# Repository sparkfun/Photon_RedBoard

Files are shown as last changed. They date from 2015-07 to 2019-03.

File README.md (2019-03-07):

SparkFun Photon RedBoard
========================================

SparkFun Photon RedBoard

[*SparkFun Photon RedBoard (DEV-13321)*](https://www.sparkfun.com/products/13321)

The SparkFun Photon RedBoard is a Particle Cloud-compatible WiFi development board. It can be programmed over-the-air, using Particle's Build IDE. It's like a Photon, but Arduino-shaped and red!

Repository Contents
-------------------

* **/Documentation** - Data sheets, additional product information
* **/Hardware** - Eagle design files (.brd, .sch)
* **/Production** - Production panel files (.brd)

Documentation
--------------
* **[Hookup Guide](https://learn.sparkfun.com/tutorials/photon-redboard-hookup-guide)** - Basic hookup guide for the SparkFun Photon RedBoard.
* **[Experiment Guide](https://learn.sparkfun.com/tutorials/photon-redboard-hookup-guide)** - Experiment guide for the SparkFun Photon RedBoard to send and receive data over WiFi.
* **[SparkFun Fritzing repo](https://github.com/sparkfun/Fritzing_Parts)** - Fritzing diagrams for SparkFun products.
* **[SparkFun 3D Model repo](https://github.com/sparkfun/3D_Models)** - 3D models of SparkFun products. 

Product Versions
----------------
* [DEV-13321](https://www.sparkfun.com/products/13321) - **Photon RedBoard**: Initial release of the SparkFun Photon RedBoard.
* [KIT-13320](https://www.sparkfun.com/products/13320) - **SparkFun Inventor's Kit for Photon**: A SparkFun Inventor's Kit based around the Photon RedBoard.

Version History
---------------
* [V_1.0](https://github.com/sparkfun/Photon_RedBoard/tree/V_1.0) - Initial hardware release - 1.0.

License Information
-------------------

This product is _**open source**_! 

Please review the LICENSE.md file for license information. 

If you have any questions or concerns on licensing, please contact techsupport@sparkfun.com.

Distributed as-is; no warranty is given.

- Your friends at SparkFun.

_<COLLABORATION CREDIT>_

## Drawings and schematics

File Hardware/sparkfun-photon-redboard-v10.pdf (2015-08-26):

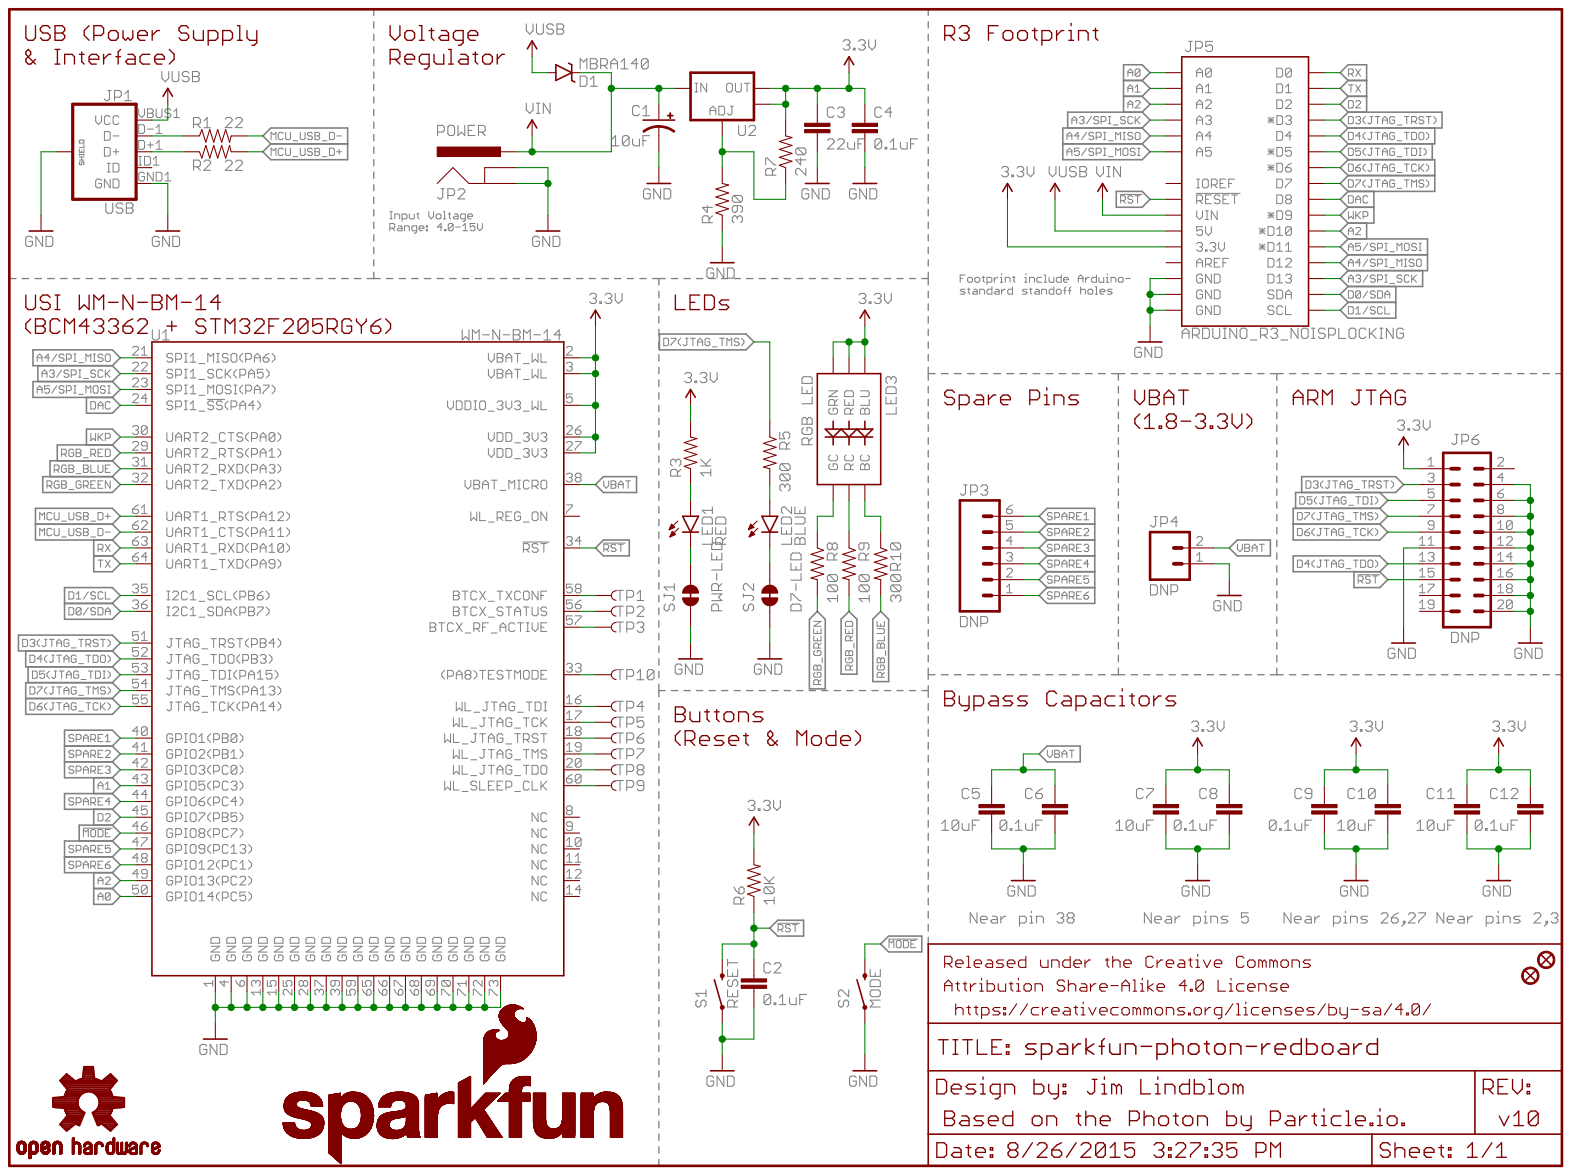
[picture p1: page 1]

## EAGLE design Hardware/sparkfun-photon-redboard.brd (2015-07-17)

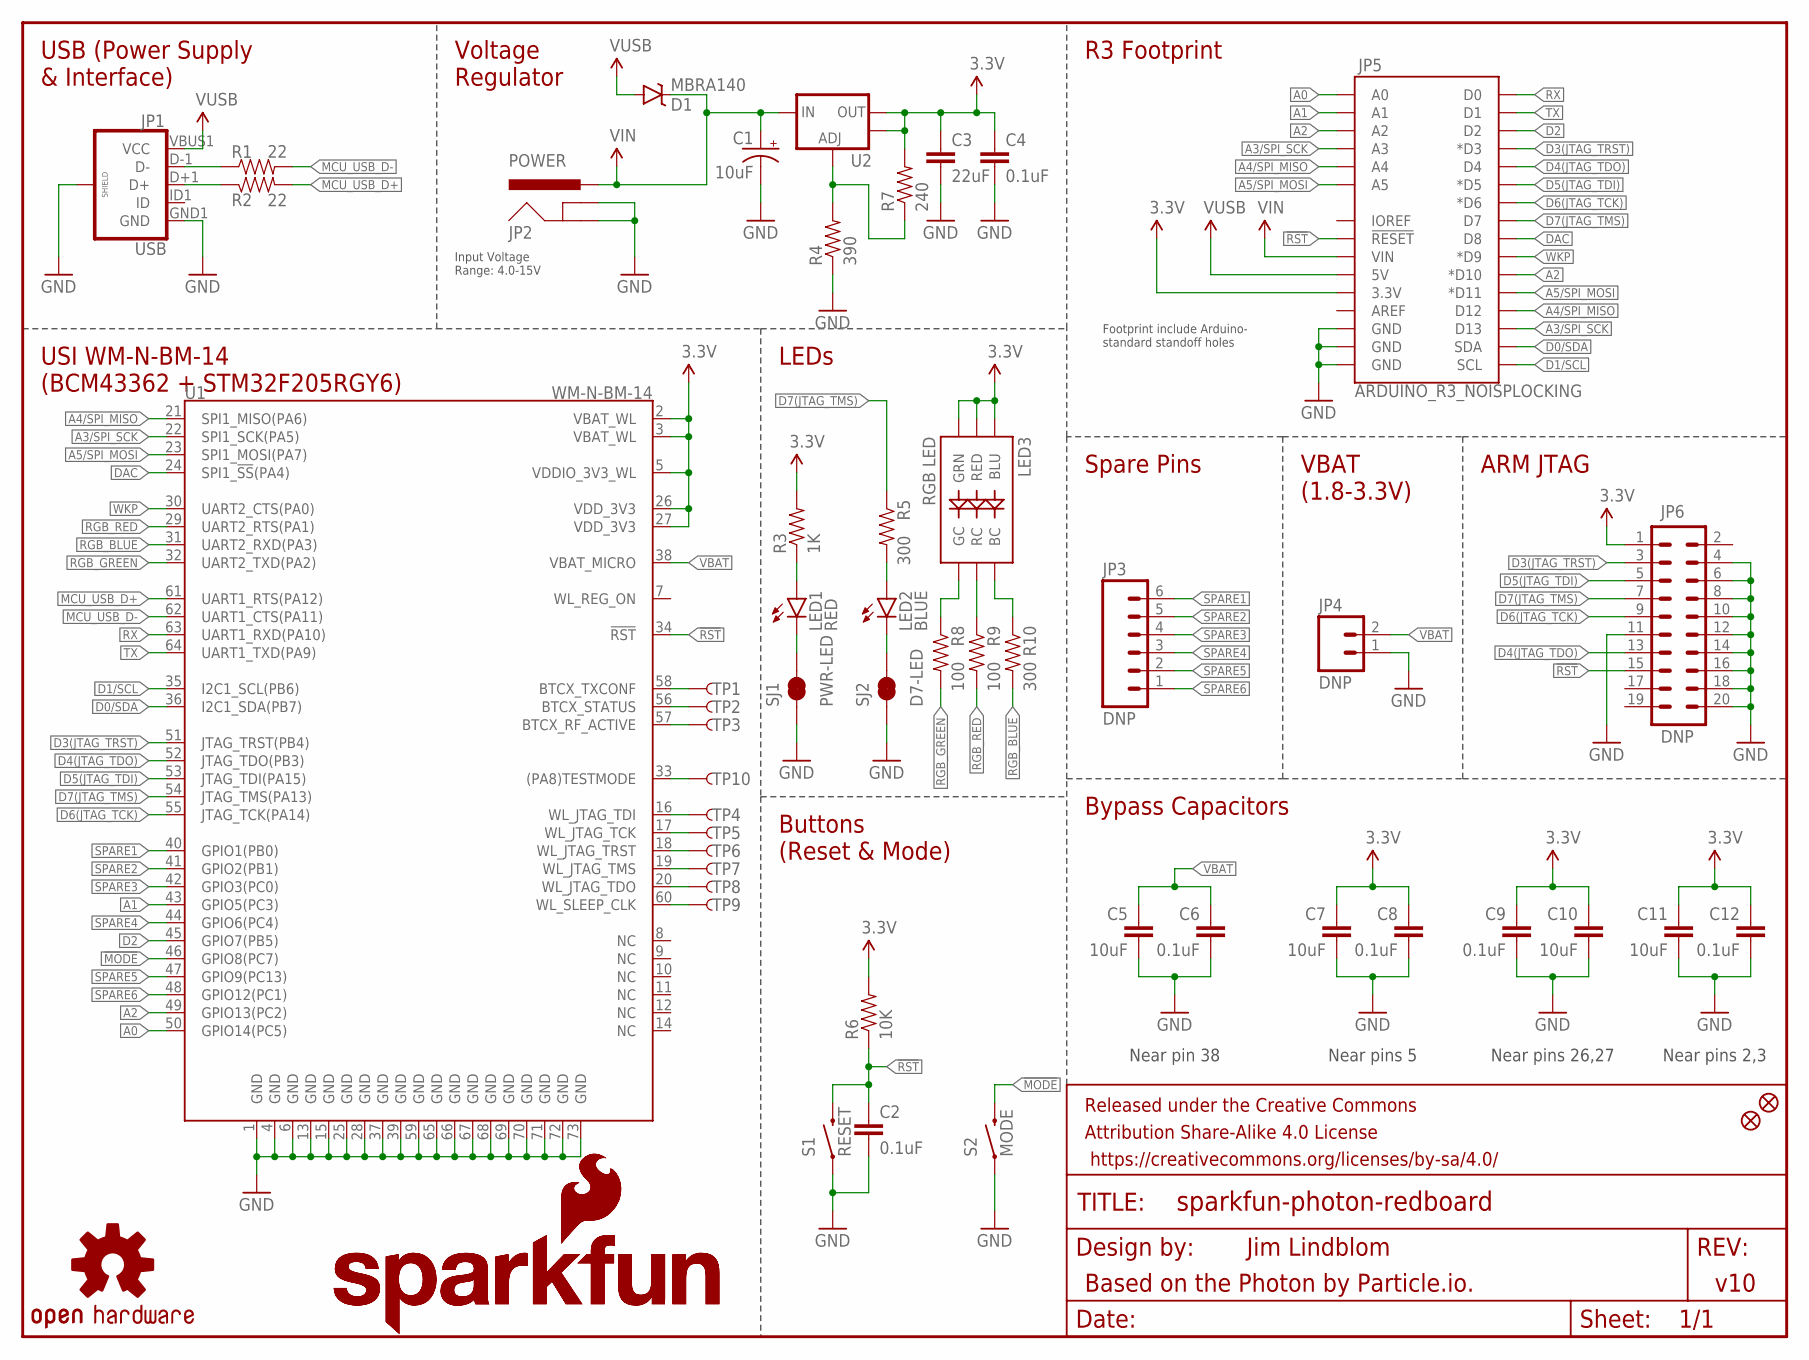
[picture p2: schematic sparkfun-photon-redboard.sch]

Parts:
C1: 10uF; EIA3216
C2, C4, C6, C8, C9, C12: 0.1uF; 0603-CAP
C3: 22uF; 0805
C5, C7, C10, C11: 10uF; 0603-CAP
D1: MBRA140; SMA-DIODE
FID1, FID2: FIDUCIAL1X2; FIDUCIAL-1X2
FRAME1: FRAME-LETTER; CREATIVE_COMMONS
JP1: USB; USB-B-MICRO-SMD_V03
JP2: POWER; POWER_JACK_PTH_LOCK
JP3: DNP; 1X06
JP4: DNP; 1X02
JP5: ARDUINO_R3_NOISPLOCKING; ARDUINO_R3_NOISP_LOCKING
JP6: DNP; 2X10
LED1: RED; LED-1206
LED2: BLUE; LED-1206
LED3: RGB LED; PLCC-6-LED
LOGO1: OSHW-LOGOM; OSHW-LOGO-M
LOGO2: SFE_LOGO_NAME_FLAME.2_INCH; SFE_LOGO_NAME_FLAME_.2
LOGO3: SFE_LOGO_NAME_FLAME.4_INCH; SFE_LOGO_NAME_FLAME_.4
R1, R2: 22; 0603-RES
R3: 1K; 0603-RES
R4: 390; 0603-RES
R5, R10: 300; 0603-RES
R6: 10K; 0603-RES
R7: 240; 0603-RES
R8, R9: 100; 0603-RES
S1: RESET; TACTILE-PTH
S2: MODE; TACTILE-PTH
SJ1: PWR-LED; PAD-JUMPER-2-NC_BY_TRACE_YES_SILK
SJ2: D7-LED; PAD-JUMPER-2-NC_BY_TRACE_YES_SILK
TP1, TP2, TP3, TP4, TP5, TP6, TP7, TP8, TP9, TP10: TEST-POINTTP_15TH_THRU; TP_15TH
U1: WM-N-BM-14
U2: V_REG_LM1117SOT223; SOT223

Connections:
3.3V: C3.1, C4.1, C7.1, C8.1, C9.1, C10.1, C11.1, C12.1, JP5.3.3V, JP6.1, LED3.AB (BLU), LED3.AG (GRN), LED3.AR (RED), R3.2, R6.2, R7.2, U1.2 (VBAT_WL), U1.3 (VBAT_WL), U1.5 (VDDIO_3V3_WL), U1.26 (VDD_3V3), U1.27 (VDD_3V3), U2.2 (OUT), U2.4 (OUT)
!MODE: S2.3 (2), U1.46 (GPIO8(PC7))
!RST: C2.1, JP5.RESET@1 (!RESET!), JP6.15, R6.1, S1.3 (2), U1.34 (!RST!)
A0: JP5.A0, U1.50 (GPIO14(PC5))
A1: JP5.A1, U1.43 (GPIO5(PC3))
A2: JP5.A2, JP5.D10 (*D10), U1.49 (GPIO13(PC2))
A3/SPI_SCK: JP5.A3, JP5.D13, U1.22 (SPI1_SCK(PA5))
A4/SPI_MISO: JP5.A4, JP5.D12, U1.21 (SPI1_MISO(PA6))
A5/SPI_MOSI: JP5.A5, JP5.D11 (*D11), U1.23 (SPI1_MOSI(PA7))
BTCX_RF_ACTIVE: TP3.P$1, U1.57 (BTCX_RF_ACTIVE)
BTCX_STATUS: TP2.P$1, U1.56 (BTCX_STATUS)
BTCX_TXCONF: TP1.P$1, U1.58 (BTCX_TXCONF)
D0/SDA: JP5.SDA, U1.36 (I2C1_SDA(PB7))
D1/SCL: JP5.SCL, U1.35 (I2C1_SCL(PB6))
D2: JP5.D2, U1.45 (GPIO7(PB5))
D3(JTAG_TRST): JP5.D3 (*D3), JP6.3, U1.51 (JTAG_TRST(PB4))
D4(JTAG_TDO): JP5.D4, JP6.13, U1.52 (JTAG_TDO(PB3))
D5(JTAG_TDI): JP5.D5 (*D5), JP6.5, U1.53 (JTAG_TDI(PA15))
D6(JTAG_TCK): JP5.D6 (*D6), JP6.9, U1.55 (JTAG_TCK(PA14))
D7(JTAG_TMS): JP5.D7, JP6.7, R5.1, U1.54 (JTAG_TMS(PA13))
D+: JP1.D+1 (D+), R2.1
D-: JP1.D-1 (D-), R1.1
DAC: JP5.D8, U1.24 (SPI1_!SS!(PA4))
GND: C1.C (-), C2.2, C3.2, C4.2, C5.2, C6.2, C7.2, C8.2, C9.2, C10.2, C11.2, C12.2, JP1.GND1 (GND), JP1.SHIELD1 (SHIELD), JP1.SHIELD2 (SHIELD), JP1.SHIELD3 (SHIELD), JP2.GND, JP2.GNDBREAK, JP4.1, JP5.GND@1 (GND), JP5.GND@2 (GND), JP5.GND@3 (GND), JP6.4, JP6.6, JP6.8, JP6.10, JP6.11, JP6.12, JP6.14, JP6.16, JP6.18, JP6.20, R4.1, S1.1, S2.1, SJ1.1, SJ2.1, U1.1 (GND), U1.4 (GND), U1.6 (GND), U1.13 (GND), U1.15 (GND), U1.25 (GND), U1.28 (GND), U1.37 (GND), U1.39 (GND), U1.59 (GND), U1.65 (GND), U1.66 (GND), U1.67 (GND), U1.68 (GND), U1.69 (GND), U1.70 (GND), U1.71 (GND), U1.72 (GND), U1.73 (GND)
MCU_USB_D+: R2.2, U1.61 (UART1_RTS(PA12))
MCU_USB_D-: R1.2, U1.62 (UART1_CTS(PA11))
unnamed: TP10.P$1, U1.33 ((PA8)TESTMODE)
unnamed: LED1.C, SJ1.2
unnamed: LED3.CG (GC), R8.1
unnamed: LED3.CR (RC), R9.1
unnamed: LED3.CB (BC), R10.1
unnamed: LED1.A, R3.1
unnamed: LED2.A, R5.2
unnamed: LED2.C, SJ2.2
unnamed: R4.2, R7.1, U2.1 (ADJ)
RGB_BLUE: R10.2, U1.31 (UART2_RXD(PA3))
RGB_GREEN: R8.2, U1.32 (UART2_TXD(PA2))
RGB_RED: R9.2, U1.29 (UART2_RTS(PA1))
RX: JP5.D0, U1.63 (UART1_RXD(PA10))
SPARE1: JP3.6, U1.40 (GPIO1(PB0))
SPARE2: JP3.5, U1.41 (GPIO2(PB1))
SPARE3: JP3.4, U1.42 (GPIO3(PC0))
SPARE4: JP3.3, U1.44 (GPIO6(PC4))
SPARE5: JP3.2, U1.47 (GPIO9(PC13))
SPARE6: JP3.1, U1.48 (GPIO12(PC1))
TX: JP5.D1, U1.64 (UART1_TXD(PA9))
VBAT: C5.1, C6.1, JP4.2, U1.38 (VBAT_MICRO)
VIN: C1.A (+), D1.C, JP2.PWR, JP5.VIN, U2.3 (IN)
VUSB: D1.A, JP1.VBUS1 (VCC), JP5.5V
WKP: JP5.D9 (*D9), U1.30 (UART2_CTS(PA0))
WL_JTAG_TCK: TP5.P$1, U1.17 (WL_JTAG_TCK)
WL_JTAG_TDI: TP4.P$1, U1.16 (WL_JTAG_TDI)
WL_JTAG_TDO: TP8.P$1, U1.20 (WL_JTAG_TDO)
WL_JTAG_TMS: TP7.P$1, U1.19 (WL_JTAG_TMS)
WL_JTAG_TRST: TP6.P$1, U1.18 (WL_JTAG_TRST)
WL_SLEEP_CLK: TP9.P$1, U1.60 (WL_SLEEP_CLK)

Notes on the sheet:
Near pin 38
Near pins 26,27
Near pins 5
Near pins 2,3
Voltage Regulator
USB (Power Supply & Interface)
R3 Footprint
Spare Pins
VBAT (1.8-3.3V)
ARM JTAG
Bypass Capacitors
LEDs
Buttons (Reset & Mode)
USI WM-N-BM-14 (BCM43362 + STM32F205RGY6)
Based on the Photon by Particle.io.
Jim Lindblom
v10
Input Voltage Range: 4.0-15V
Footprint include Arduino- standard standoff holes

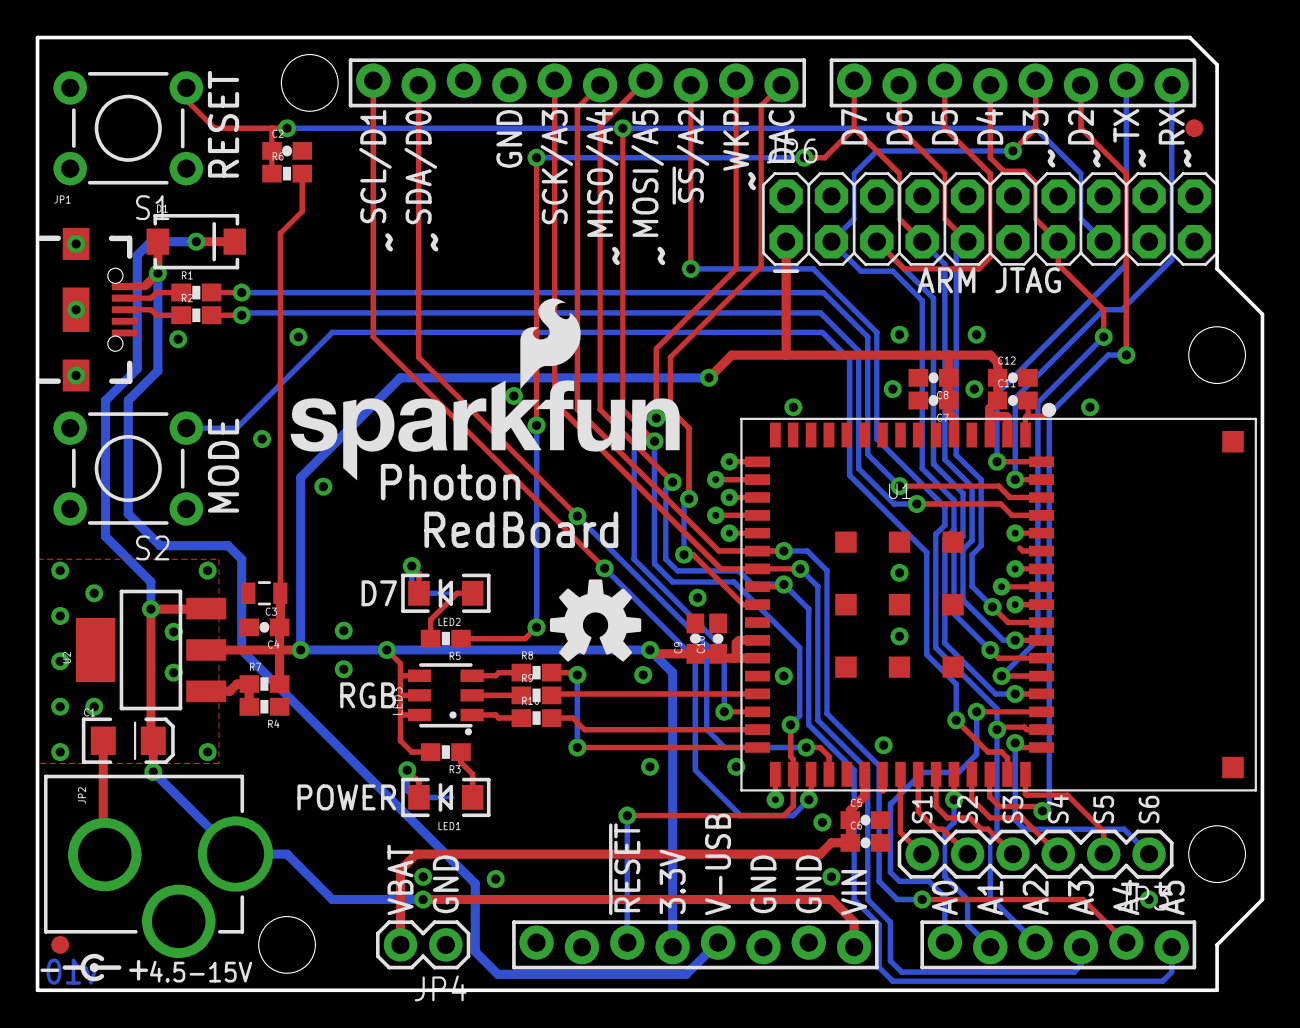
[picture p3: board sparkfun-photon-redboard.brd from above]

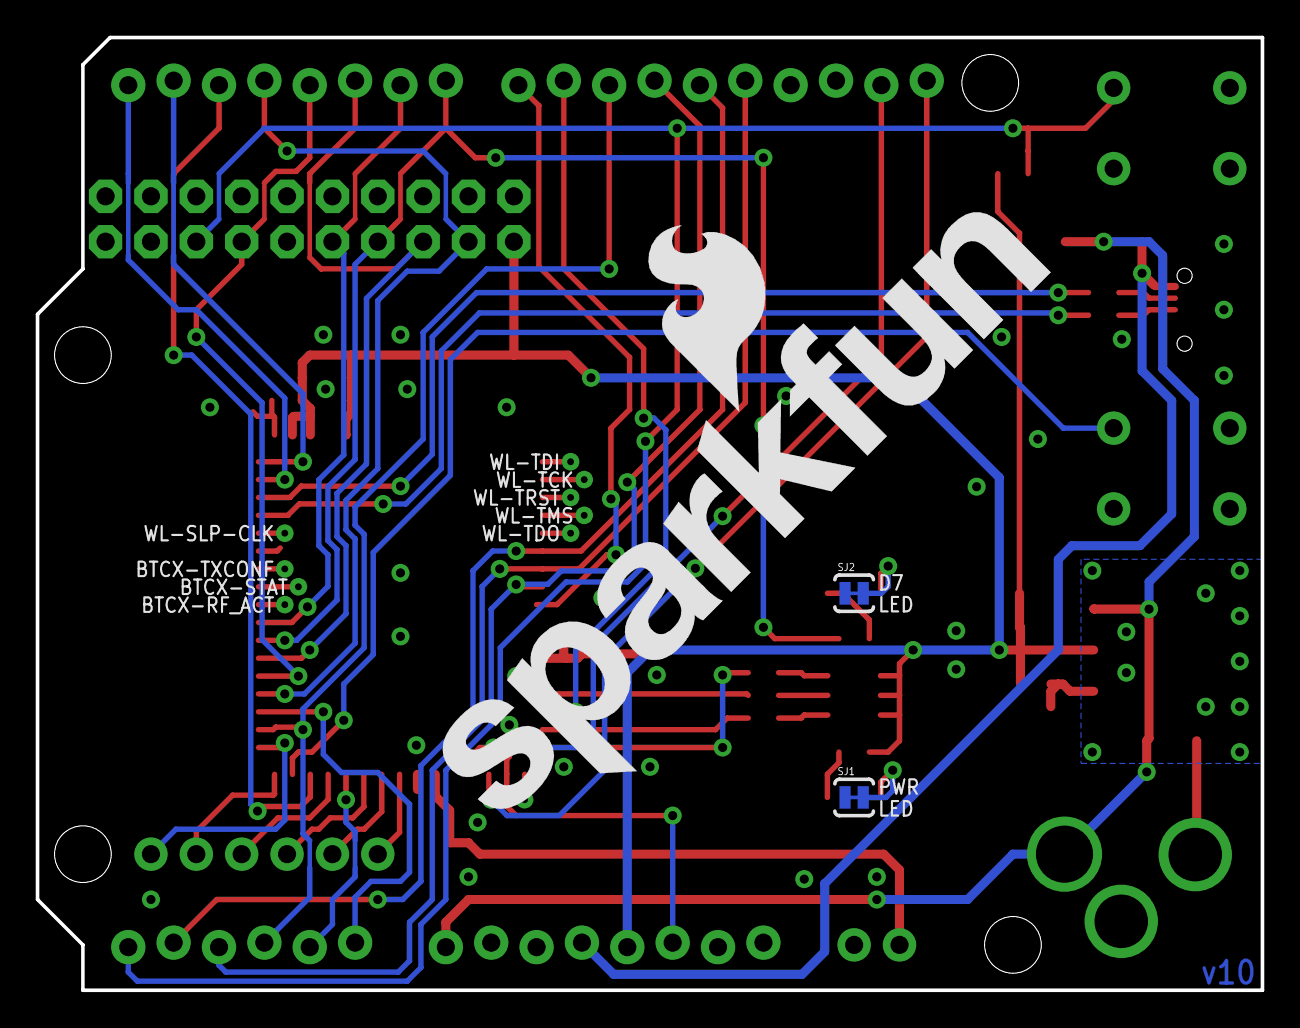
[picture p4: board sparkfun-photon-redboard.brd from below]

Board: 2 copper layers, 68.6 x 53.3 mm, 54 parts (4 on the bottom side), 56 nets.

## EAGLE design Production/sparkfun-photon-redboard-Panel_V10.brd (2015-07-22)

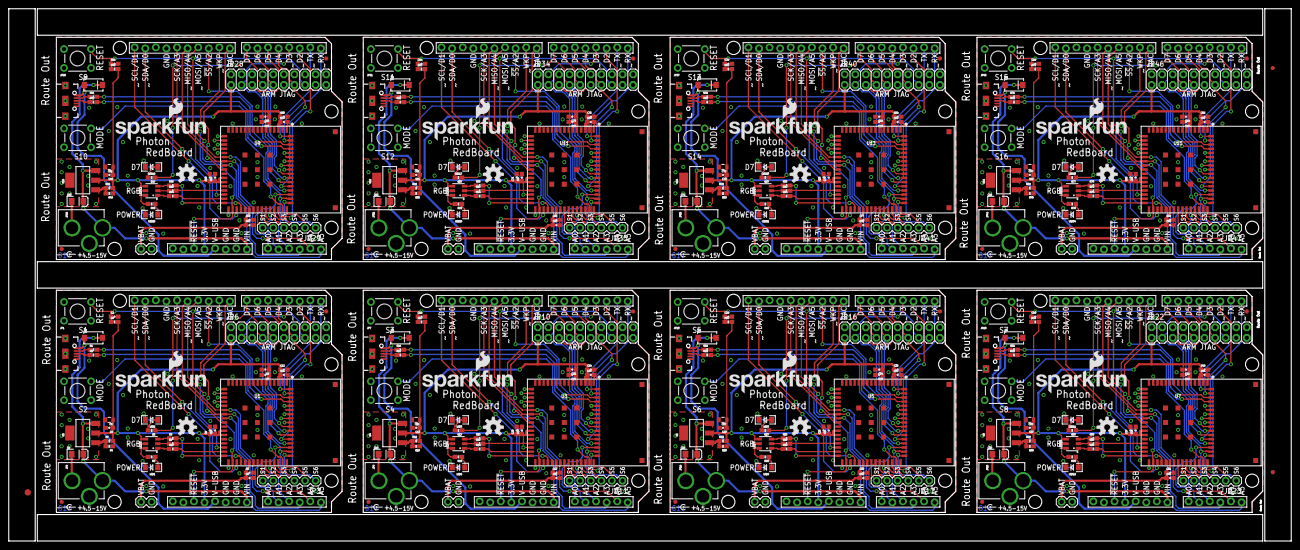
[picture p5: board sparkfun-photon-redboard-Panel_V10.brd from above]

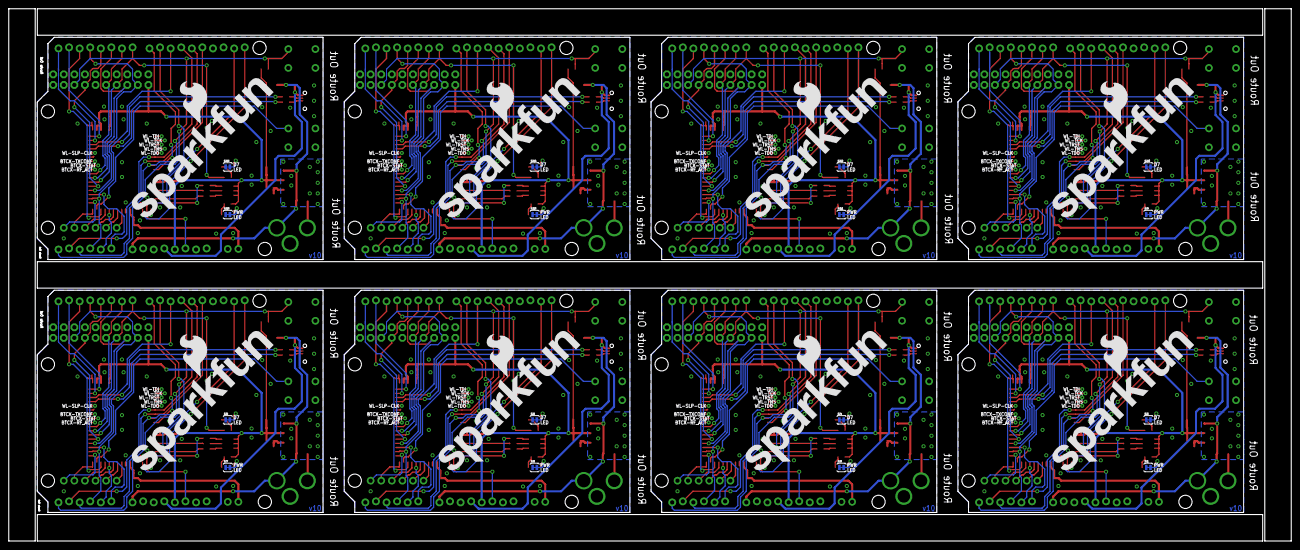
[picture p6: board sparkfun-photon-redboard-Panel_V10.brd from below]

Board: 2 copper layers, 307.8 x 127.8 mm, 427 parts (32 on the bottom side), 448 nets.

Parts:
C1, C14, C26, C38, C50, C62, C74, C86: 10uF; EIA3216
C2, C4, C6, C8, C9, C12, C13, C16, C21, C22, C23, C24, C25, C28, C33, C34, C35, C36, C37, C40, C45, C46, C47, C48, C49, C52, C57, C58, C59, C60, C61, C64, C69, C70, C71, C72, C73, C76, C81, C82, C83, C84, C85, C88, C93, C94, C95, C96: 0.1uF; 0603-CAP
C3, C15, C27, C39, C51, C63, C75, C87: 22uF; 0805
C5, C7, C10, C11, C17, C18, C19, C20, C29, C30, C31, C32, C41, C42, C43, C44, C53, C54, C55, C56, C65, C66, C67, C68, C77, C78, C79, C80, C89, C90, C91, C92: 10uF; 0603-CAP
D1, D2, D3, D4, D5, D6, D7, D8: MBRA140; SMA-DIODE
E$1: FIDUCIAL-1.5X3
E$7, E$8: FIDUCIAL-1X2
FID1, FID2, FID3, FID4, FID5, FID6, FID7, FID8, FID9, FID10, FID11, FID12, FID13, FID14, FID15, FID16: FIDUCIAL1X2; FIDUCIAL-1X2
JP1, JP7, JP13, JP19, JP25, JP31, JP37, JP43: USB; USB-B-MICRO-SMD_V03
JP2, JP8, JP14, JP20, JP26, JP32, JP38, JP44: POWER; POWER_JACK_PTH_LOCK
JP3, JP11, JP17, JP23, JP29, JP35, JP41, JP47: DNP; 1X06
JP4, JP12, JP18, JP24, JP30, JP36, JP42, JP48: DNP; 1X02
JP5, JP9, JP15, JP21, JP27, JP33, JP39, JP45: ARDUINO_R3_NOISPLOCKING; ARDUINO_R3_NOISP_LOCKING
JP6, JP10, JP16, JP22, JP28, JP34, JP40, JP46: DNP; 2X10
LED1, LED6, LED9, LED12, LED15, LED18, LED21, LED24: RED; LED-1206
LED2, LED5, LED8, LED11, LED14, LED17, LED20, LED23: BLUE; LED-1206
LED3, LED4, LED7, LED10, LED13, LED16, LED19, LED22: RGB LED; PLCC-6-LED
LOGO1, LOGO5, LOGO8, LOGO11, LOGO14, LOGO17, LOGO20, LOGO23: OSHW-LOGOM; OSHW-LOGO-M
LOGO2, LOGO4, LOGO7, LOGO10, LOGO13, LOGO16, LOGO19, LOGO22: SFE_LOGO_NAME_FLAME.2_INCH; SFE_LOGO_NAME_FLAME_.2
LOGO3, LOGO6, LOGO9, LOGO12, LOGO15, LOGO18, LOGO21, LOGO24: SFE_LOGO_NAME_FLAME.4_INCH; SFE_LOGO_NAME_FLAME_.4
R1, R2, R11, R12, R21, R22, R31, R32, R41, R42, R51, R52, R61, R62, R71, R72: 22; 0603-RES
R3, R18, R28, R38, R48, R58, R68, R78: 1K; 0603-RES
R4, R19, R29, R39, R49, R59, R69, R79: 390; 0603-RES
R5, R10, R14, R17, R24, R27, R34, R37, R44, R47, R54, R57, R64, R67, R74, R77: 300; 0603-RES
R6, R13, R23, R33, R43, R53, R63, R73: 10K; 0603-RES
R7, R20, R30, R40, R50, R60, R70, R80: 240; 0603-RES
R8, R9, R15, R16, R25, R26, R35, R36, R45, R46, R55, R56, R65, R66, R75, R76: 100; 0603-RES
S1, S3, S5, S7, S9, S11, S13, S15: RESET; TACTILE-PTH
S2, S4, S6, S8, S10, S12, S14, S16: MODE; TACTILE-PTH
SJ1, SJ3, SJ5, SJ7, SJ9, SJ11, SJ13, SJ15: PWR-LED; PAD-JUMPER-2-NC_BY_TRACE_YES_SILK
SJ2, SJ4, SJ6, SJ8, SJ10, SJ12, SJ14, SJ16: D7-LED; PAD-JUMPER-2-NC_BY_TRACE_YES_SILK
TP1, TP2, TP3, TP4, TP5, TP6, TP7, TP8, TP9, TP10, TP11, TP12, TP13, TP14, TP15, TP16, TP17, TP18, TP19, TP20, TP21, TP22, TP23, TP24, TP25, TP26, TP27, TP28, TP29, TP30, TP31, TP32, TP33, TP34, TP35, TP36, TP37, TP38, TP39, TP40, TP41, TP42, TP43, TP44, TP45, TP46, TP47, TP48, TP49, TP50, TP51, TP52, TP53, TP54, TP55, TP56, TP57, TP58, TP59, TP60, TP61, TP62, TP63, TP64, TP65, TP66, TP67, TP68, TP69, TP70, TP71, TP72, TP73, TP74, TP75, TP76, TP77, TP78, TP79, TP80: TEST-POINTTP_15TH_THRU; TP_15TH
U1, U3, U5, U7, U9, U11, U13, U15: WM-N-BM-14
U2, U4, U6, U8, U10, U12, U14, U16: SOT223

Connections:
3.3V: C3.1, C4.1, C7.1, C8.1, C9.1, C10.1, C11.1, C12.1, JP5.3.3V, JP6.1, LED3.AB, LED3.AG, LED3.AR, R3.2, R6.2, R7.2, U1.2, U1.3, U1.5, U1.26, U1.27, U2.2, U2.4
3.3V1: C13.1, C15.1, C18.1, C19.1, C20.1, C22.1, C23.1, C24.1, JP9.3.3V, JP10.1, LED4.AB, LED4.AG, LED4.AR, R13.2, R18.2, R20.2, U3.2, U3.3, U3.5, U3.26, U3.27, U4.2, U4.4
3.3V2: C25.1, C27.1, C30.1, C31.1, C32.1, C34.1, C35.1, C36.1, JP15.3.3V, JP16.1, LED7.AB, LED7.AG, LED7.AR, R23.2, R28.2, R30.2, U5.2, U5.3, U5.5, U5.26, U5.27, U6.2, U6.4
3.3V3: C37.1, C39.1, C42.1, C43.1, C44.1, C46.1, C47.1, C48.1, JP21.3.3V, JP22.1, LED10.AB, LED10.AG, LED10.AR, R33.2, R38.2, R40.2, U7.2, U7.3, U7.5, U7.26, U7.27, U8.2, U8.4
3.3V4: C49.1, C51.1, C54.1, C55.1, C56.1, C58.1, C59.1, C60.1, JP27.3.3V, JP28.1, LED13.AB, LED13.AG, LED13.AR, R43.2, R48.2, R50.2, U9.2, U9.3, U9.5, U9.26, U9.27, U10.2, U10.4
3.3V5: C61.1, C63.1, C66.1, C67.1, C68.1, C70.1, C71.1, C72.1, JP33.3.3V, JP34.1, LED16.AB, LED16.AG, LED16.AR, R53.2, R58.2, R60.2, U11.2, U11.3, U11.5, U11.26, U11.27, U12.2, U12.4
3.3V6: C73.1, C75.1, C78.1, C79.1, C80.1, C82.1, C83.1, C84.1, JP39.3.3V, JP40.1, LED19.AB, LED19.AG, LED19.AR, R63.2, R68.2, R70.2, U13.2, U13.3, U13.5, U13.26, U13.27, U14.2, U14.4
3.3V7: C85.1, C87.1, C90.1, C91.1, C92.1, C94.1, C95.1, C96.1, JP45.3.3V, JP46.1, LED22.AB, LED22.AG, LED22.AR, R73.2, R78.2, R80.2, U15.2, U15.3, U15.5, U15.26, U15.27, U16.2, U16.4
!MODE: S2.3, U1.46
!MODE1: S4.3, U3.46
!MODE2: S6.3, U5.46
!MODE3: S8.3, U7.46
!MODE4: S10.3, U9.46
!MODE5: S12.3, U11.46
!MODE6: S14.3, U13.46
!MODE7: S16.3, U15.46
!RST: C2.1, JP5.RESET@1, JP6.15, R6.1, S1.3, U1.34
!RST1: C16.1, JP9.RESET@1, JP10.15, R13.1, S3.3, U3.34
!RST2: C28.1, JP15.RESET@1, JP16.15, R23.1, S5.3, U5.34
!RST3: C40.1, JP21.RESET@1, JP22.15, R33.1, S7.3, U7.34
!RST4: C52.1, JP27.RESET@1, JP28.15, R43.1, S9.3, U9.34
!RST5: C64.1, JP33.RESET@1, JP34.15, R53.1, S11.3, U11.34
!RST6: C76.1, JP39.RESET@1, JP40.15, R63.1, S13.3, U13.34
!RST7: C88.1, JP45.RESET@1, JP46.15, R73.1, S15.3, U15.34
A0: JP5.A0, U1.50
A1: JP5.A1, U1.43
A2: JP5.A2, JP5.D10, U1.49
A3: JP9.A2, JP9.D10, U3.49
A3/SPI_SCK: JP5.A3, JP5.D13, U1.22
A3/SPI_SCK1: JP9.A3, JP9.D13, U3.22
A3/SPI_SCK2: JP15.A3, JP15.D13, U5.22
A3/SPI_SCK3: JP21.A3, JP21.D13, U7.22
A3/SPI_SCK4: JP27.A3, JP27.D13, U9.22
A3/SPI_SCK5: JP33.A3, JP33.D13, U11.22
A3/SPI_SCK6: JP39.A3, JP39.D13, U13.22
A3/SPI_SCK7: JP45.A3, JP45.D13, U15.22
A4: JP9.A1, U3.43
A4/SPI_MISO: JP5.A4, JP5.D12, U1.21
A4/SPI_MISO1: JP9.A4, JP9.D12, U3.21
A4/SPI_MISO2: JP15.A4, JP15.D12, U5.21
A4/SPI_MISO3: JP21.A4, JP21.D12, U7.21
A4/SPI_MISO4: JP27.A4, JP27.D12, U9.21
A4/SPI_MISO5: JP33.A4, JP33.D12, U11.21
A4/SPI_MISO6: JP39.A4, JP39.D12, U13.21
A4/SPI_MISO7: JP45.A4, JP45.D12, U15.21
A5: JP9.A0, U3.50
A5/SPI_MOSI: JP5.A5, JP5.D11, U1.23
A5/SPI_MOSI1: JP9.A5, JP9.D11, U3.23
A5/SPI_MOSI2: JP15.A5, JP15.D11, U5.23
A5/SPI_MOSI3: JP21.A5, JP21.D11, U7.23
A5/SPI_MOSI4: JP27.A5, JP27.D11, U9.23
A5/SPI_MOSI5: JP33.A5, JP33.D11, U11.23
A5/SPI_MOSI6: JP39.A5, JP39.D11, U13.23
A5/SPI_MOSI7: JP45.A5, JP45.D11, U15.23
A6: JP15.A2, JP15.D10, U5.49
A7: JP15.A1, U5.43
A8: JP15.A0, U5.50
A9: JP21.A2, JP21.D10, U7.49
A10: JP21.A1, U7.43
A11: JP21.A0, U7.50
A12: JP27.A2, JP27.D10, U9.49
A13: JP27.A1, U9.43
A14: JP27.A0, U9.50
A15: JP33.A2, JP33.D10, U11.49
A16: JP33.A1, U11.43
A17: JP33.A0, U11.50
A18: JP39.A2, JP39.D10, U13.49
A19: JP39.A1, U13.43
A20: JP39.A0, U13.50
A21: JP45.A2, JP45.D10, U15.49
A22: JP45.A1, U15.43
A23: JP45.A0, U15.50
BTCX_RF_ACTIVE: TP3.P$1, U1.57
BTCX_RF_ACTIVE1: TP11.P$1, U3.57
BTCX_RF_ACTIVE2: TP21.P$1, U5.57
BTCX_RF_ACTIVE3: TP31.P$1, U7.57
BTCX_RF_ACTIVE4: TP41.P$1, U9.57
BTCX_RF_ACTIVE5: TP51.P$1, U11.57
BTCX_RF_ACTIVE6: TP61.P$1, U13.57
BTCX_RF_ACTIVE7: TP71.P$1, U15.57
BTCX_STATUS: TP2.P$1, U1.56
BTCX_STATUS1: TP13.P$1, U3.56
BTCX_STATUS2: TP23.P$1, U5.56
BTCX_STATUS3: TP33.P$1, U7.56
BTCX_STATUS4: TP43.P$1, U9.56
BTCX_STATUS5: TP53.P$1, U11.56
BTCX_STATUS6: TP63.P$1, U13.56
BTCX_STATUS7: TP73.P$1, U15.56
BTCX_TXCONF: TP1.P$1, U1.58
BTCX_TXCONF1: TP12.P$1, U3.58
BTCX_TXCONF2: TP22.P$1, U5.58
BTCX_TXCONF3: TP32.P$1, U7.58
BTCX_TXCONF4: TP42.P$1, U9.58
BTCX_TXCONF5: TP52.P$1, U11.58
BTCX_TXCONF6: TP62.P$1, U13.58
BTCX_TXCONF7: TP72.P$1, U15.58
D0/SDA: JP5.SDA, U1.36
D0/SDA1: JP9.SDA, U3.36
D0/SDA2: JP15.SDA, U5.36
D0/SDA3: JP21.SDA, U7.36
D0/SDA4: JP27.SDA, U9.36
D0/SDA5: JP33.SDA, U11.36
D0/SDA6: JP39.SDA, U13.36
D0/SDA7: JP45.SDA, U15.36
D1: JP9.D2, U3.45
D1/SCL: JP5.SCL, U1.35
D1/SCL1: JP9.SCL, U3.35
D1/SCL2: JP15.SCL, U5.35
D1/SCL3: JP21.SCL, U7.35
D1/SCL4: JP27.SCL, U9.35
D1/SCL5: JP33.SCL, U11.35
D1/SCL6: JP39.SCL, U13.35
D1/SCL7: JP45.SCL, U15.35
D2: JP5.D2, U1.45
D3: JP15.D2, U5.45
D3(JTAG_TRST): JP5.D3, JP6.3, U1.51
D3(JTAG_TRST)1: JP9.D3, JP10.3, U3.51
D3(JTAG_TRST)2: JP15.D3, JP16.3, U5.51
D3(JTAG_TRST)3: JP21.D3, JP22.3, U7.51
D3(JTAG_TRST)4: JP27.D3, JP28.3, U9.51
D3(JTAG_TRST)5: JP33.D3, JP34.3, U11.51
D3(JTAG_TRST)6: JP39.D3, JP40.3, U13.51
D3(JTAG_TRST)7: JP45.D3, JP46.3, U15.51
D4: JP21.D2, U7.45
D4(JTAG_TDO): JP5.D4, JP6.13, U1.52
D4(JTAG_TDO)1: JP9.D4, JP10.13, U3.52
D4(JTAG_TDO)2: JP15.D4, JP16.13, U5.52
D4(JTAG_TDO)3: JP21.D4, JP22.13, U7.52
D4(JTAG_TDO)4: JP27.D4, JP28.13, U9.52
D4(JTAG_TDO)5: JP33.D4, JP34.13, U11.52
D4(JTAG_TDO)6: JP39.D4, JP40.13, U13.52
D4(JTAG_TDO)7: JP45.D4, JP46.13, U15.52
D5: JP27.D2, U9.45
D5(JTAG_TDI): JP5.D5, JP6.5, U1.53
D5(JTAG_TDI)1: JP9.D5, JP10.5, U3.53
D5(JTAG_TDI)2: JP15.D5, JP16.5, U5.53
D5(JTAG_TDI)3: JP21.D5, JP22.5, U7.53
D5(JTAG_TDI)4: JP27.D5, JP28.5, U9.53
D5(JTAG_TDI)5: JP33.D5, JP34.5, U11.53
D5(JTAG_TDI)6: JP39.D5, JP40.5, U13.53
D5(JTAG_TDI)7: JP45.D5, JP46.5, U15.53
D6: JP33.D2, U11.45
D6(JTAG_TCK): JP5.D6, JP6.9, U1.55
D6(JTAG_TCK)1: JP9.D6, JP10.9, U3.55
D6(JTAG_TCK)2: JP15.D6, JP16.9, U5.55
D6(JTAG_TCK)3: JP21.D6, JP22.9, U7.55
D6(JTAG_TCK)4: JP27.D6, JP28.9, U9.55
D6(JTAG_TCK)5: JP33.D6, JP34.9, U11.55
D6(JTAG_TCK)6: JP39.D6, JP40.9, U13.55
D6(JTAG_TCK)7: JP45.D6, JP46.9, U15.55
D7: JP39.D2, U13.45
D7(JTAG_TMS): JP5.D7, JP6.7, R5.1, U1.54
D7(JTAG_TMS)1: JP9.D7, JP10.7, R17.1, U3.54
D7(JTAG_TMS)2: JP15.D7, JP16.7, R27.1, U5.54
D7(JTAG_TMS)3: JP21.D7, JP22.7, R37.1, U7.54
D7(JTAG_TMS)4: JP27.D7, JP28.7, R47.1, U9.54
D7(JTAG_TMS)5: JP33.D7, JP34.7, R57.1, U11.54
D7(JTAG_TMS)6: JP39.D7, JP40.7, R67.1, U13.54
D7(JTAG_TMS)7: JP45.D7, JP46.7, R77.1, U15.54
D8: JP45.D2, U15.45
D+: JP1.D+1, R2.1
D+1: JP7.D+1, R12.1
D+2: JP13.D+1, R22.1
D+3: JP19.D+1, R32.1
D+4: JP25.D+1, R42.1
D+5: JP31.D+1, R52.1
D+6: JP37.D+1, R62.1
D+7: JP43.D+1, R72.1
D-: JP1.D-1, R1.1
D-1: JP7.D-1, R11.1
D-2: JP13.D-1, R21.1
D-3: JP19.D-1, R31.1
D-4: JP25.D-1, R41.1
D-5: JP31.D-1, R51.1
D-6: JP37.D-1, R61.1
D-7: JP43.D-1, R71.1
DAC: JP5.D8, U1.24
DAC1: JP9.D8, U3.24
DAC2: JP15.D8, U5.24
DAC3: JP21.D8, U7.24
DAC4: JP27.D8, U9.24
DAC5: JP33.D8, U11.24
DAC6: JP39.D8, U13.24
DAC7: JP45.D8, U15.24
GND: C1.C, C2.2, C3.2, C4.2, C5.2, C6.2, C7.2, C8.2, C9.2, C10.2, C11.2, C12.2, JP1.GND1, JP1.SHIELD1, JP1.SHIELD2, JP1.SHIELD3, JP2.GND, JP2.GNDBREAK, JP4.1, JP5.GND@1, JP5.GND@2, JP5.GND@3, JP6.4, JP6.6, JP6.8, JP6.10, JP6.11, JP6.12, JP6.14, JP6.16, JP6.18, JP6.20, R4.1, S1.1, S2.1, SJ1.1, SJ2.1, U1.1, U1.4, U1.6, U1.13, U1.15, U1.25, U1.28, U1.37, U1.39, U1.59, U1.65, U1.66, U1.67, U1.68, U1.69, U1.70, U1.71, U1.72, U1.73
GND1: C13.2, C14.C, C15.2, C16.2, C17.2, C18.2, C19.2, C20.2, C21.2, C22.2, C23.2, C24.2, JP7.GND1, JP7.SHIELD1, JP7.SHIELD2, JP7.SHIELD3, JP8.GND, JP8.GNDBREAK, JP9.GND@1, JP9.GND@2, JP9.GND@3, JP10.4, JP10.6, JP10.8, JP10.10, JP10.11, JP10.12, JP10.14, JP10.16, JP10.18, JP10.20, JP12.1, R19.1, S3.1, S4.1, SJ3.1, SJ4.1, U3.1, U3.4, U3.6, U3.13, U3.15, U3.25, U3.28, U3.37, U3.39, U3.59, U3.65, U3.66, U3.67, U3.68, U3.69, U3.70, U3.71, U3.72, U3.73
GND2: C25.2, C26.C, C27.2, C28.2, C29.2, C30.2, C31.2, C32.2, C33.2, C34.2, C35.2, C36.2, JP13.GND1, JP13.SHIELD1, JP13.SHIELD2, JP13.SHIELD3, JP14.GND, JP14.GNDBREAK, JP15.GND@1, JP15.GND@2, JP15.GND@3, JP16.4, JP16.6, JP16.8, JP16.10, JP16.11, JP16.12, JP16.14, JP16.16, JP16.18, JP16.20, JP18.1, R29.1, S5.1, S6.1, SJ5.1, SJ6.1, U5.1, U5.4, U5.6, U5.13, U5.15, U5.25, U5.28, U5.37, U5.39, U5.59, U5.65, U5.66, U5.67, U5.68, U5.69, U5.70, U5.71, U5.72, U5.73
GND3: C37.2, C38.C, C39.2, C40.2, C41.2, C42.2, C43.2, C44.2, C45.2, C46.2, C47.2, C48.2, JP19.GND1, JP19.SHIELD1, JP19.SHIELD2, JP19.SHIELD3, JP20.GND, JP20.GNDBREAK, JP21.GND@1, JP21.GND@2, JP21.GND@3, JP22.4, JP22.6, JP22.8, JP22.10, JP22.11, JP22.12, JP22.14, JP22.16, JP22.18, JP22.20, JP24.1, R39.1, S7.1, S8.1, SJ7.1, SJ8.1, U7.1, U7.4, U7.6, U7.13, U7.15, U7.25, U7.28, U7.37, U7.39, U7.59, U7.65, U7.66, U7.67, U7.68, U7.69, U7.70, U7.71, U7.72, U7.73
GND4: C49.2, C50.C, C51.2, C52.2, C53.2, C54.2, C55.2, C56.2, C57.2, C58.2, C59.2, C60.2, JP25.GND1, JP25.SHIELD1, JP25.SHIELD2, JP25.SHIELD3, JP26.GND, JP26.GNDBREAK, JP27.GND@1, JP27.GND@2, JP27.GND@3, JP28.4, JP28.6, JP28.8, JP28.10, JP28.11, JP28.12, JP28.14, JP28.16, JP28.18, JP28.20, JP30.1, R49.1, S9.1, S10.1, SJ9.1, SJ10.1, U9.1, U9.4, U9.6, U9.13, U9.15, U9.25, U9.28, U9.37, U9.39, U9.59, U9.65, U9.66, U9.67, U9.68, U9.69, U9.70, U9.71, U9.72, U9.73
GND5: C61.2, C62.C, C63.2, C64.2, C65.2, C66.2, C67.2, C68.2, C69.2, C70.2, C71.2, C72.2, JP31.GND1, JP31.SHIELD1, JP31.SHIELD2, JP31.SHIELD3, JP32.GND, JP32.GNDBREAK, JP33.GND@1, JP33.GND@2, JP33.GND@3, JP34.4, JP34.6, JP34.8, JP34.10, JP34.11, JP34.12, JP34.14, JP34.16, JP34.18, JP34.20, JP36.1, R59.1, S11.1, S12.1, SJ11.1, SJ12.1, U11.1, U11.4, U11.6, U11.13, U11.15, U11.25, U11.28, U11.37, U11.39, U11.59, U11.65, U11.66, U11.67, U11.68, U11.69, U11.70, U11.71, U11.72, U11.73
GND6: C73.2, C74.C, C75.2, C76.2, C77.2, C78.2, C79.2, C80.2, C81.2, C82.2, C83.2, C84.2, JP37.GND1, JP37.SHIELD1, JP37.SHIELD2, JP37.SHIELD3, JP38.GND, JP38.GNDBREAK, JP39.GND@1, JP39.GND@2, JP39.GND@3, JP40.4, JP40.6, JP40.8, JP40.10, JP40.11, JP40.12, JP40.14, JP40.16, JP40.18, JP40.20, JP42.1, R69.1, S13.1, S14.1, SJ13.1, SJ14.1, U13.1, U13.4, U13.6, U13.13, U13.15, U13.25, U13.28, U13.37, U13.39, U13.59, U13.65, U13.66, U13.67, U13.68, U13.69, U13.70, U13.71, U13.72, U13.73
GND7: C85.2, C86.C, C87.2, C88.2, C89.2, C90.2, C91.2, C92.2, C93.2, C94.2, C95.2, C96.2, JP43.GND1, JP43.SHIELD1, JP43.SHIELD2, JP43.SHIELD3, JP44.GND, JP44.GNDBREAK, JP45.GND@1, JP45.GND@2, JP45.GND@3, JP46.4, JP46.6, JP46.8, JP46.10, JP46.11, JP46.12, JP46.14, JP46.16, JP46.18, JP46.20, JP48.1, R79.1, S15.1, S16.1, SJ15.1, SJ16.1, U15.1, U15.4, U15.6, U15.13, U15.15, U15.25, U15.28, U15.37, U15.39, U15.59, U15.65, U15.66, U15.67, U15.68, U15.69, U15.70, U15.71, U15.72, U15.73
MCU_USB_D+: R2.2, U1.61
MCU_USB_D+1: R12.2, U3.61
MCU_USB_D+2: R22.2, U5.61
MCU_USB_D+3: R32.2, U7.61
MCU_USB_D+4: R42.2, U9.61
MCU_USB_D+5: R52.2, U11.61
MCU_USB_D+6: R62.2, U13.61
MCU_USB_D+7: R72.2, U15.61
MCU_USB_D-: R1.2, U1.62
MCU_USB_D-1: R11.2, U3.62
MCU_USB_D-2: R21.2, U5.62
MCU_USB_D-3: R31.2, U7.62
MCU_USB_D-4: R41.2, U9.62
MCU_USB_D-5: R51.2, U11.62
MCU_USB_D-6: R61.2, U13.62
MCU_USB_D-7: R71.2, U15.62
unnamed: TP10.P$1, U1.33
unnamed: LED1.C, SJ1.2
unnamed: LED3.CG, R8.1
unnamed: LED3.CR, R9.1
unnamed: LED3.CB, R10.1
unnamed: LED1.A, R3.1
unnamed: LED2.A, R5.2
unnamed: LED2.C, SJ2.2
unnamed: R19.2, R20.1, U4.1
unnamed: LED4.CG, R16.1
unnamed: LED4.CR, R15.1
unnamed: LED4.CB, R14.1
unnamed: LED5.A, R17.2
unnamed: LED6.A, R18.1
unnamed: R4.2, R7.1, U2.1
unnamed: TP20.P$1, U3.33
unnamed: LED6.C, SJ3.2
unnamed: LED5.C, SJ4.2
unnamed: R29.2, R30.1, U6.1
unnamed: LED7.CG, R26.1
unnamed: LED7.CR, R25.1
unnamed: LED7.CB, R24.1
unnamed: LED8.A, R27.2
unnamed: LED9.A, R28.1
unnamed: TP30.P$1, U5.33
unnamed: LED9.C, SJ5.2
unnamed: LED8.C, SJ6.2
unnamed: R39.2, R40.1, U8.1
unnamed: LED10.CG, R36.1
unnamed: LED10.CR, R35.1
unnamed: LED10.CB, R34.1
unnamed: LED11.A, R37.2
unnamed: LED12.A, R38.1
unnamed: TP40.P$1, U7.33
unnamed: LED12.C, SJ7.2
unnamed: LED11.C, SJ8.2
unnamed: R49.2, R50.1, U10.1
unnamed: LED13.CG, R46.1
unnamed: LED13.CR, R45.1
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

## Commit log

2015-03-09 Initial commit of hardware.
    [sparkfun-photon_p1.brd, sparkfun-photon_p1.sch]
2015-03-09 Adding PROD_ID to USB connector.
    [sparkfun-photon_p1.brd, sparkfun-photon_p1.sch]
2015-03-10 Added measurements. Re-routed corner pins, moved JP3 away from standoff.
    [sparkfun-photon_p1.brd, sparkfun-photon_p1.sch]
2015-03-10 Moving silk indicator on P1. Labeling RGB LED. Re-routing some grounds.
    [sparkfun-photon_p1.brd, sparkfun-photon_p1.sch]
2015-03-10 Fixing tiny airwire.
    [sparkfun-photon_p1.brd]
2015-03-12 Moving a few vias for a more complete ground plane. Adjusting some silk.
    [sparkfun-photon_p1.brd]
2015-04-03 Swap WKP & RGB red signals. Add tp's to WL JTAG.
    [sparkfun-photon_p1.brd, sparkfun-photon_p1.sch]
2015-06-05 Swapping PA1 and PA0 (Red RGB and WKP pins).
    [sparkfun-photon_p1.brd, sparkfun-photon_p1.sch]
2015-06-05 Renaming extra pins to S1-S6 (SPARE).
    [sparkfun-photon_p1.brd, sparkfun-photon_p1.sch]
2015-06-05 Adding jumper to disconnect Power LED.
    [sparkfun-photon_p1.brd, sparkfun-photon_p1.sch]
2015-06-05 Changing Arduino headers to locking footprints.
    [sparkfun-photon_p1.brd, sparkfun-photon_p1.sch]
2015-06-30 Tweaking some silkscreen
    - Changing DAC to "DAC/A6"
    - Moving board name silk.
    [sparkfun-photon_p1.brd]
2015-07-10 Adding jumper to disconnect D7 LED.
    [sparkfun-photon_p1.brd, sparkfun-photon_p1.sch]
2015-07-10 Swapping WKP and DAC pins (maps PWM better).
    [sparkfun-photon_p1.brd, sparkfun-photon_p1.sch]
2015-07-10 Moving vias to avoid silk.
    [sparkfun-photon_p1.brd, sparkfun-photon_p1.sch]
2015-07-17 Cleaning up VIN trace.
    [sparkfun-photon_p1.brd]
2015-07-22 created panel v10
    [sparkfun-photon_p1_Panel_v10.brd]
2015-08-26 Renaming files to match new directory name.
    [sparkfun-photon-redboard-Panel_V10.brd, sparkfun-photon-redboard.brd, sparkfun-photon-redboard.sch]
2015-08-26 Adding v10 schematic pdf.

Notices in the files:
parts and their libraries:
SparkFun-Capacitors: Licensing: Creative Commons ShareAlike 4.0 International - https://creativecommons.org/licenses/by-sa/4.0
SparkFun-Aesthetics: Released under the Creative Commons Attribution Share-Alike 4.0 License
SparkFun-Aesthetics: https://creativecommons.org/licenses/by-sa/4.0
